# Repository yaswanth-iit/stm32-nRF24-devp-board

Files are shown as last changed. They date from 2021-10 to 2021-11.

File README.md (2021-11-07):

# STM32-nRF24 RF devpelopment board
This repository contains STM32 nRF24 development board schematics, PCB layout, output files (Designed using kiCAD) [4-Layer]

[Schematics](https://raw.githubusercontent.com/yaswanth-iit/stm32-nRF24-devp-board/master/quick%20view/schematics-stm32-nrf24.pdf)

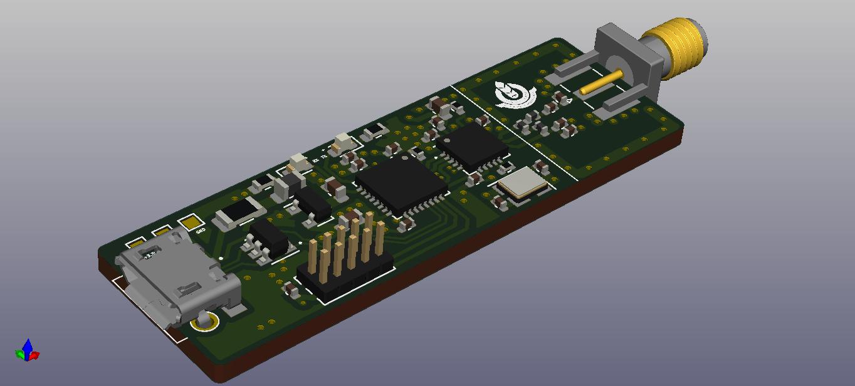
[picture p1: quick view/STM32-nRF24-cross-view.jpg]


# Top View

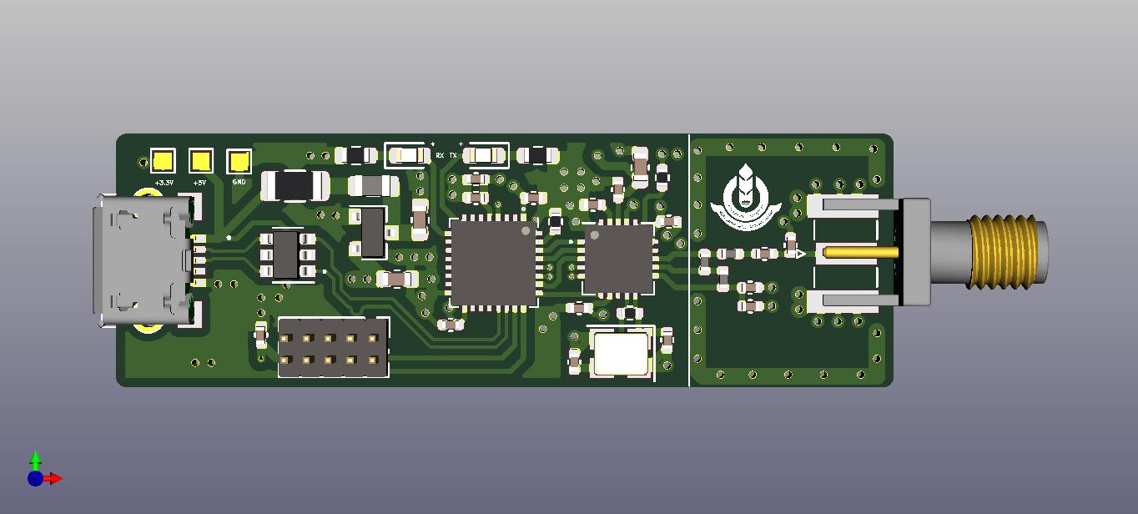
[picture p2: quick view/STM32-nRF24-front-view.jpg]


# Bottom view

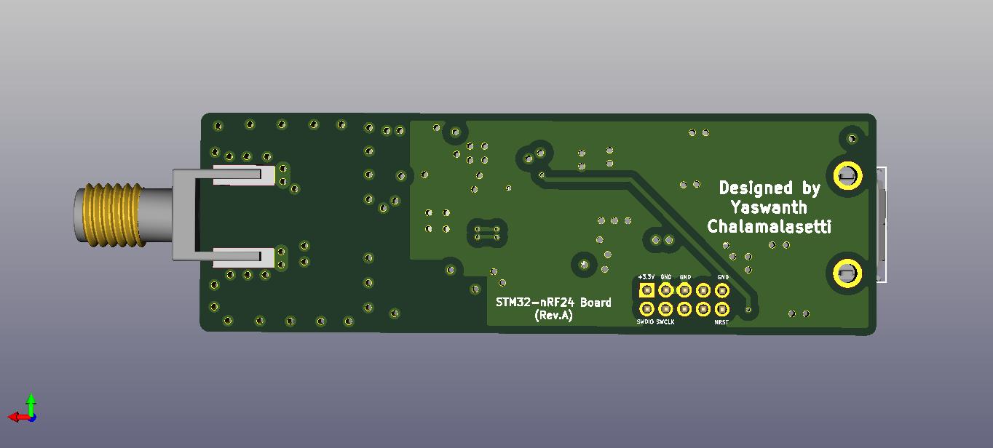
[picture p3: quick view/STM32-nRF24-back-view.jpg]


# PCB Layout

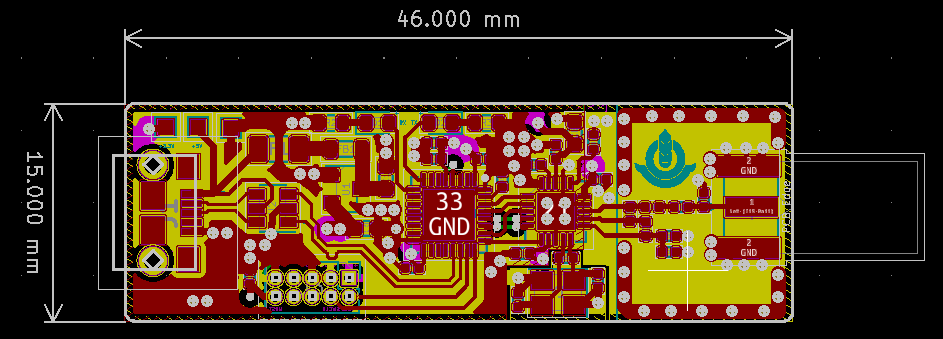
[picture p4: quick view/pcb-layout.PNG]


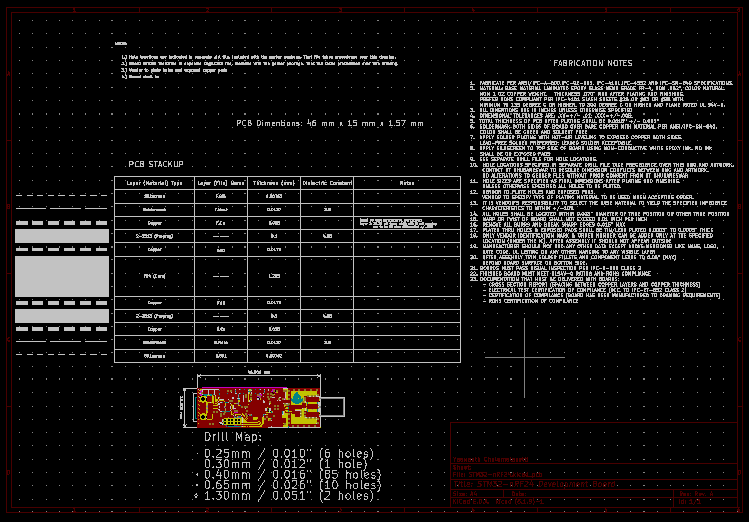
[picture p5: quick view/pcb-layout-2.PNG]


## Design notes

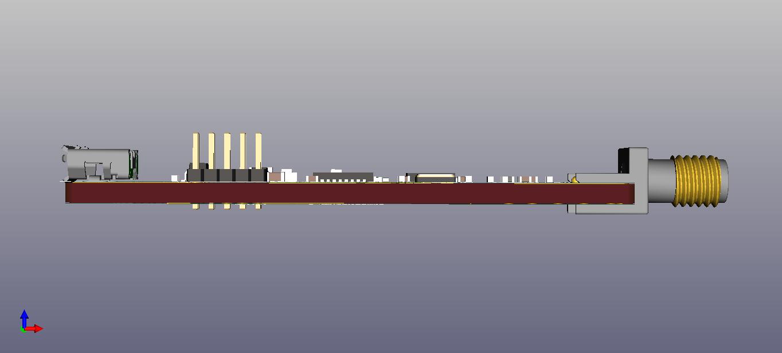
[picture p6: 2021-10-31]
quick view/STM32-nRF24-side-view.jpg

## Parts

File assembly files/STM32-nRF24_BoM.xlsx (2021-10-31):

Item | Qty | Reference(s) | Value | Description | Component name : PCB footprint | Manufacturer | Part Number | Availability status | Distributor
1 | 3 | C1, C2, C8, | 10u | Unpolarized capacitor | Capacitor_SMD:C_0603_1608Metric
2 | 4 | C3, C5, C6, C7, | 100n | Unpolarized capacitor | Capacitor_SMD:C_0402_1005Metric
3 | 1 | C4, | 1u | Unpolarized capacitor | Capacitor_SMD:C_0402_1005Metric
4 | 3 | C9, C10, C11, | 10n | Unpolarized capacitor | Capacitor_SMD:C_0402_1005Metric
5 | 1 | C12, | 33n | Unpolarized capacitor | Capacitor_SMD:C_0402_1005Metric
6 | 2 | C13, C14, | 12p | Unpolarized capacitor | Capacitor_SMD:C_0402_1005Metric
7 | 1 | C15, | 1p5 | Unpolarized capacitor | Capacitor_SMD:C_0402_1005Metric
8 | 1 | C16, | 1p | Unpolarized capacitor | Capacitor_SMD:C_0402_1005Metric
9 | 1 | C17, | 2n2 | Unpolarized capacitor | Capacitor_SMD:C_0402_1005Metric
10 | 1 | C18, | 4p7 | Unpolarized capacitor | Capacitor_SMD:C_0402_1005Metric
11 | 1 | D1, | GR | Light emitting diode | LED_SMD:LED_0603_1608Metric
12 | 1 | D2, | YE | Light emitting diode | LED_SMD:LED_0603_1608Metric
13 | 1 | F1, | 100mA | Fuse | Fuse:Fuse_1206_3216Metric
14 | 1 | FB1, | 100 @ 100MHz | Ferrite bead | Inductor_SMD:L_0805_2012Metric
15 | 1 | J1, | USB_B_Micro | USB Micro Type B connector | 10118193-0001LF:101181930001LF
16 | 1 | J2, | SMA | coaxial connector (BNC, SMA, SMB, SMC, Cinch/RCA, ...) | Connector_Coaxial:SMA_Samtec_SMA-J-P-X-ST-EM1_EdgeMount
17 | 1 | J3, | ARM 10pin | Generic connector, double row, 02x05, odd/even pin numbering scheme (row 1 odd numbers, row 2 even numbers), script generated (kicad-library-utils/schlib/autogen/connector/) | Connector_PinHeader_1.27mm:PinHeader_2x05_P1.27mm_Vertical
18 | 1 | L1, | 3n9 | Inductor | Inductor_SMD:L_0402_1005Metric
19 | 1 | L2, | 8n2 | Inductor | Inductor_SMD:L_0402_1005Metric
20 | 1 | L3, | 2n7 | Inductor | Inductor_SMD:L_0402_1005Metric
21 | 1 | R1, | 10k | Resistor | Resistor_SMD:R_0402_1005Metric
22 | 2 | R2, R3, | 2k2 | Resistor | Resistor_SMD:R_0603_1608Metric
23 | 1 | R4, | 22k | Resistor | Resistor_SMD:R_0402_1005Metric
24 | 1 | R5, | 1M | Resistor | Resistor_SMD:R_0402_1005Metric
25 | 1 | U1, | XC6206P332MR | Positive 60-250mA Low Dropout Regulator, Fixed Output, SOT-23 | Package_TO_SOT_SMD:SOT-23
26 | 1 | U2, | USBLC6-2SC6 | Very low capacitance ESD protection diode, 2 data-line, SOT-23-6 | Package_TO_SOT_SMD:SOT-23-6
27 | 1 | U3, | STM32L432KBU6 | ARM Cortex-M4 MCU, 128KB flash, 64KB RAM, 80MHz, 1.71-3.6V, 26 GPIO, UFQFPN-32 | Package_DFN_QFN:QFN-32-1EP_5x5mm_P0.5mm_EP3.45x3.45mm
28 | 1 | U4, | nRF24L01P | nRF24L01+, Ultra low power 2.4GHz RF Transceiver, QFN20 4x4mm | Package_DFN_QFN:QFN-20-1EP_4x4mm_P0.5mm_EP2.5x2.5mm
29 | 1 | Y1, | 16MHz | Four pin crystal, GND on pins 2 and 4, small symbol | Crystal:Crystal_SMD_3225-4Pin_3.2x2.5mm

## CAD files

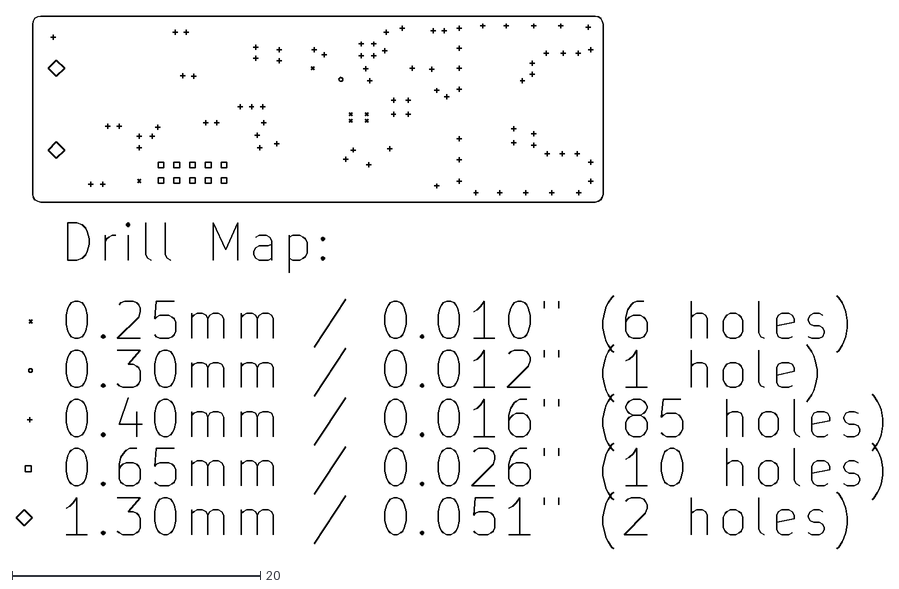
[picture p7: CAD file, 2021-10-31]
kicad-sch-pcb-files/STM32-nRF24-drl_map.dxf
69.9 x 43.0

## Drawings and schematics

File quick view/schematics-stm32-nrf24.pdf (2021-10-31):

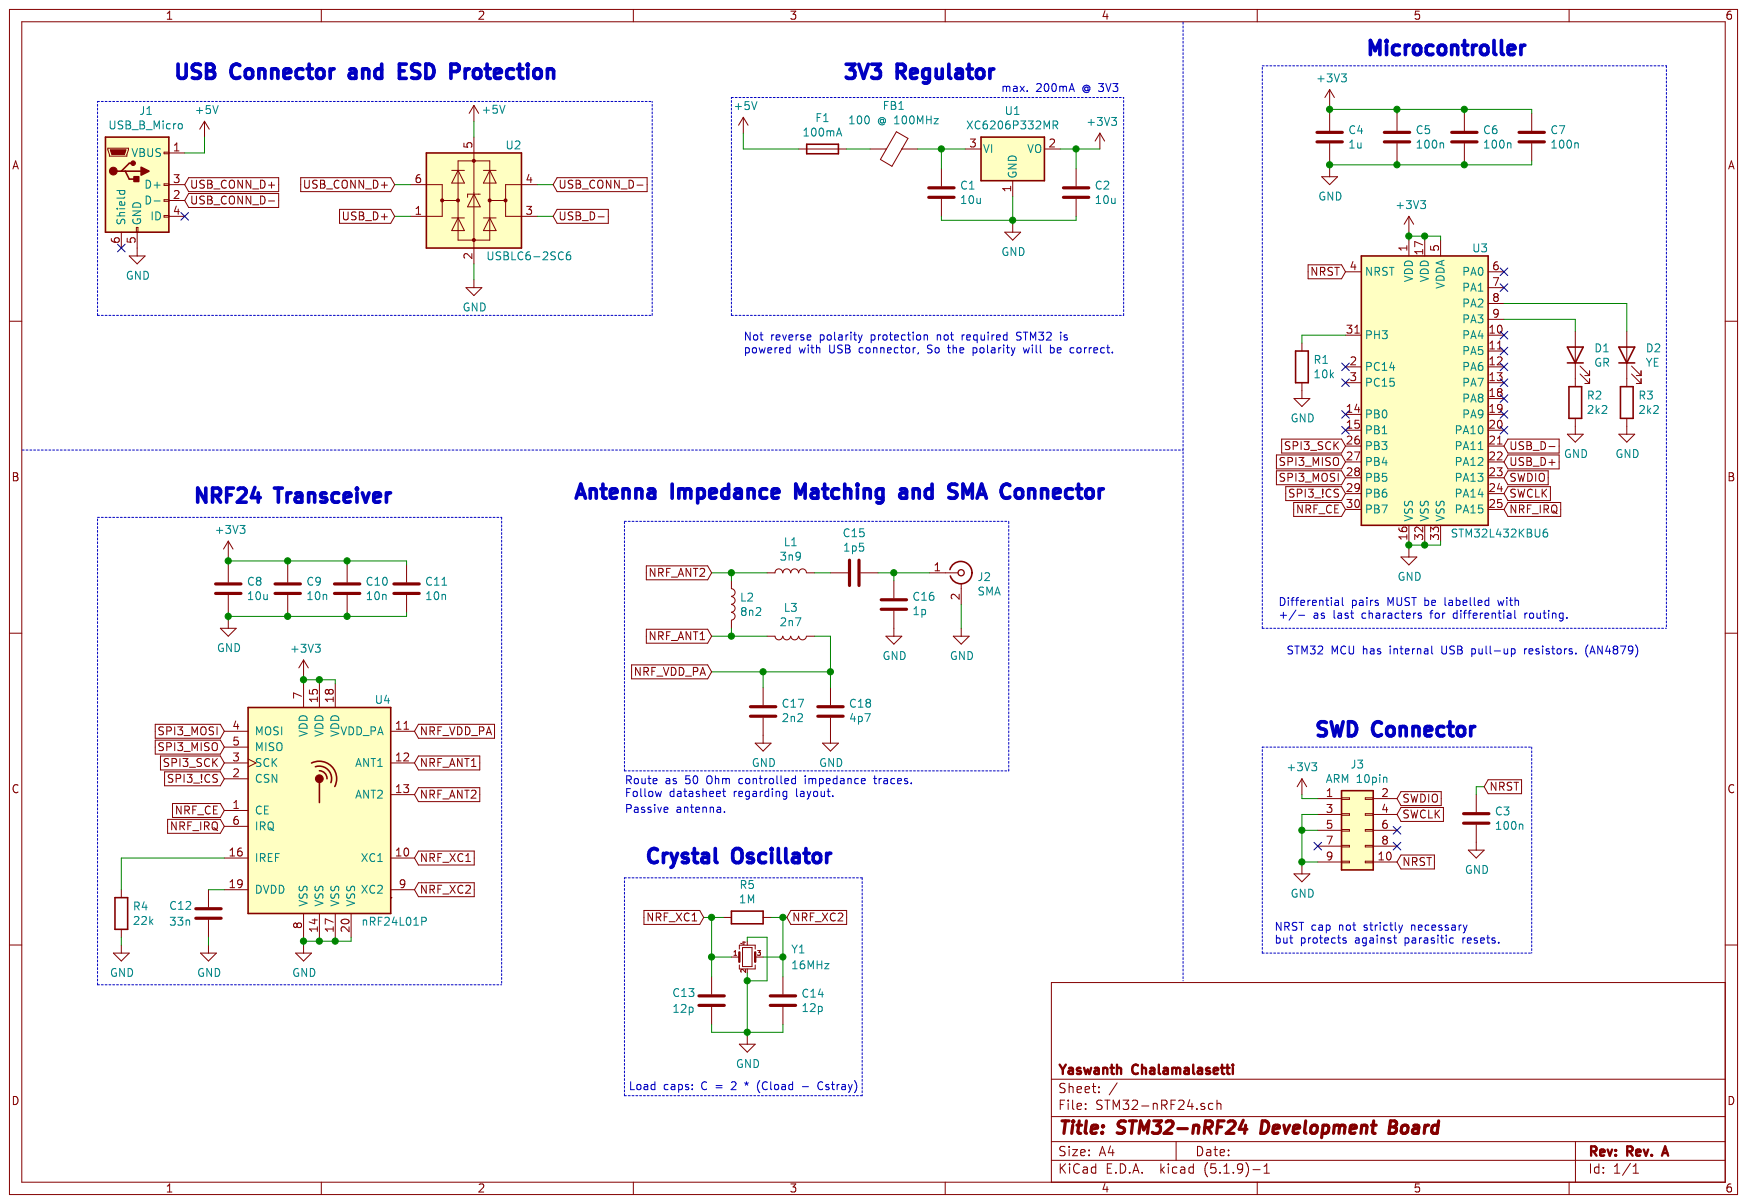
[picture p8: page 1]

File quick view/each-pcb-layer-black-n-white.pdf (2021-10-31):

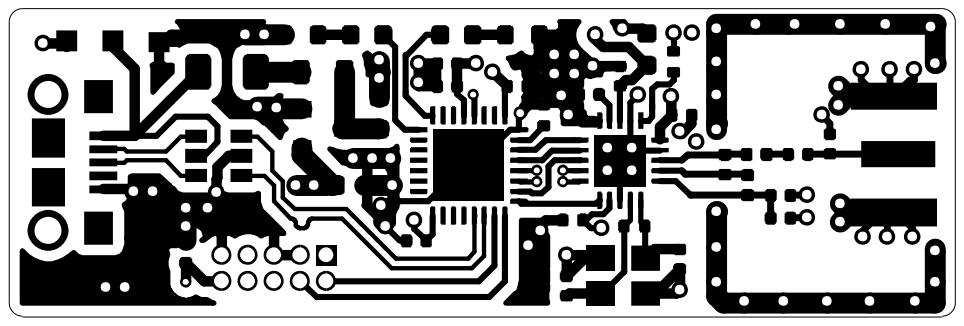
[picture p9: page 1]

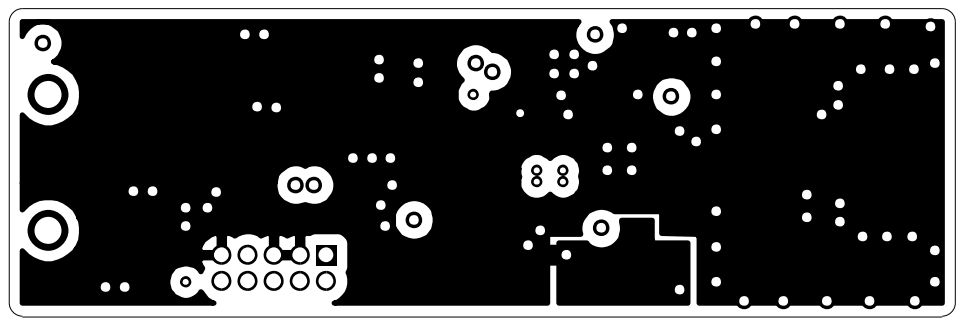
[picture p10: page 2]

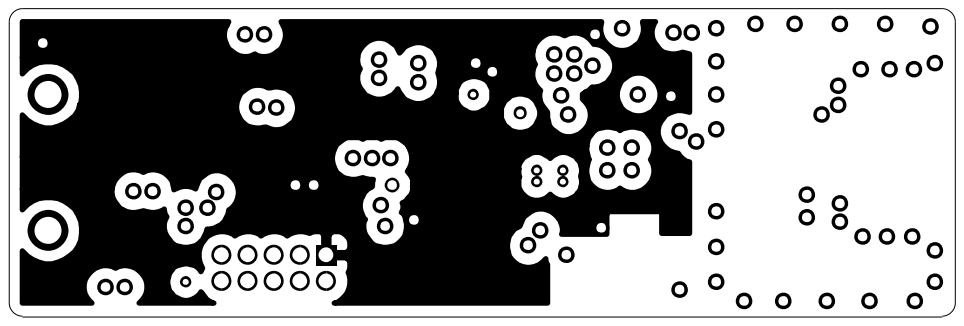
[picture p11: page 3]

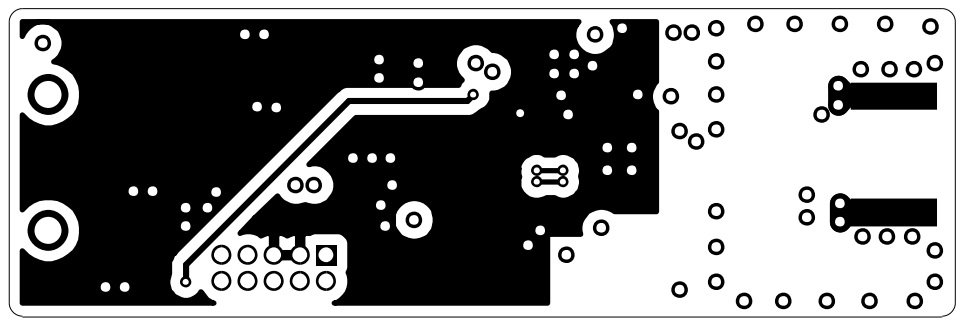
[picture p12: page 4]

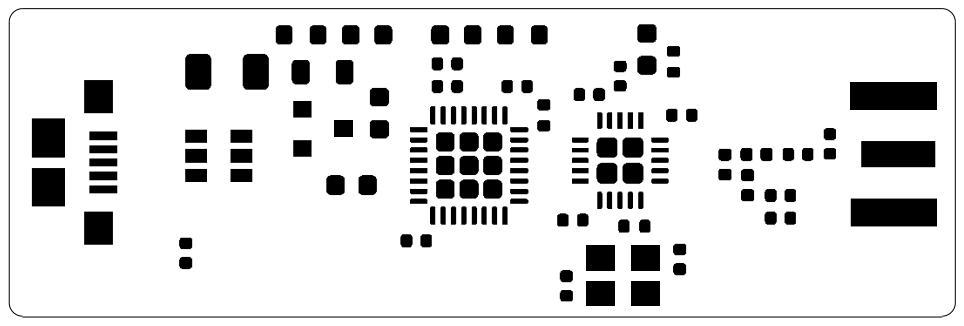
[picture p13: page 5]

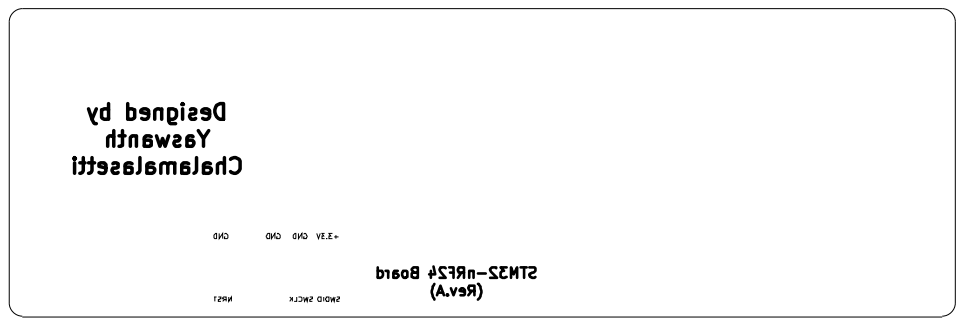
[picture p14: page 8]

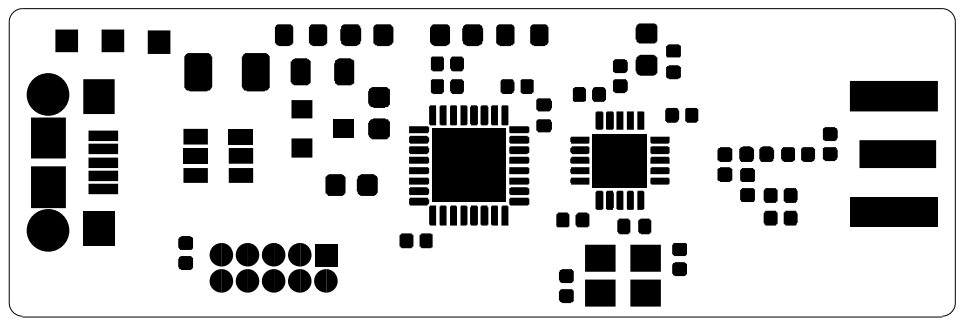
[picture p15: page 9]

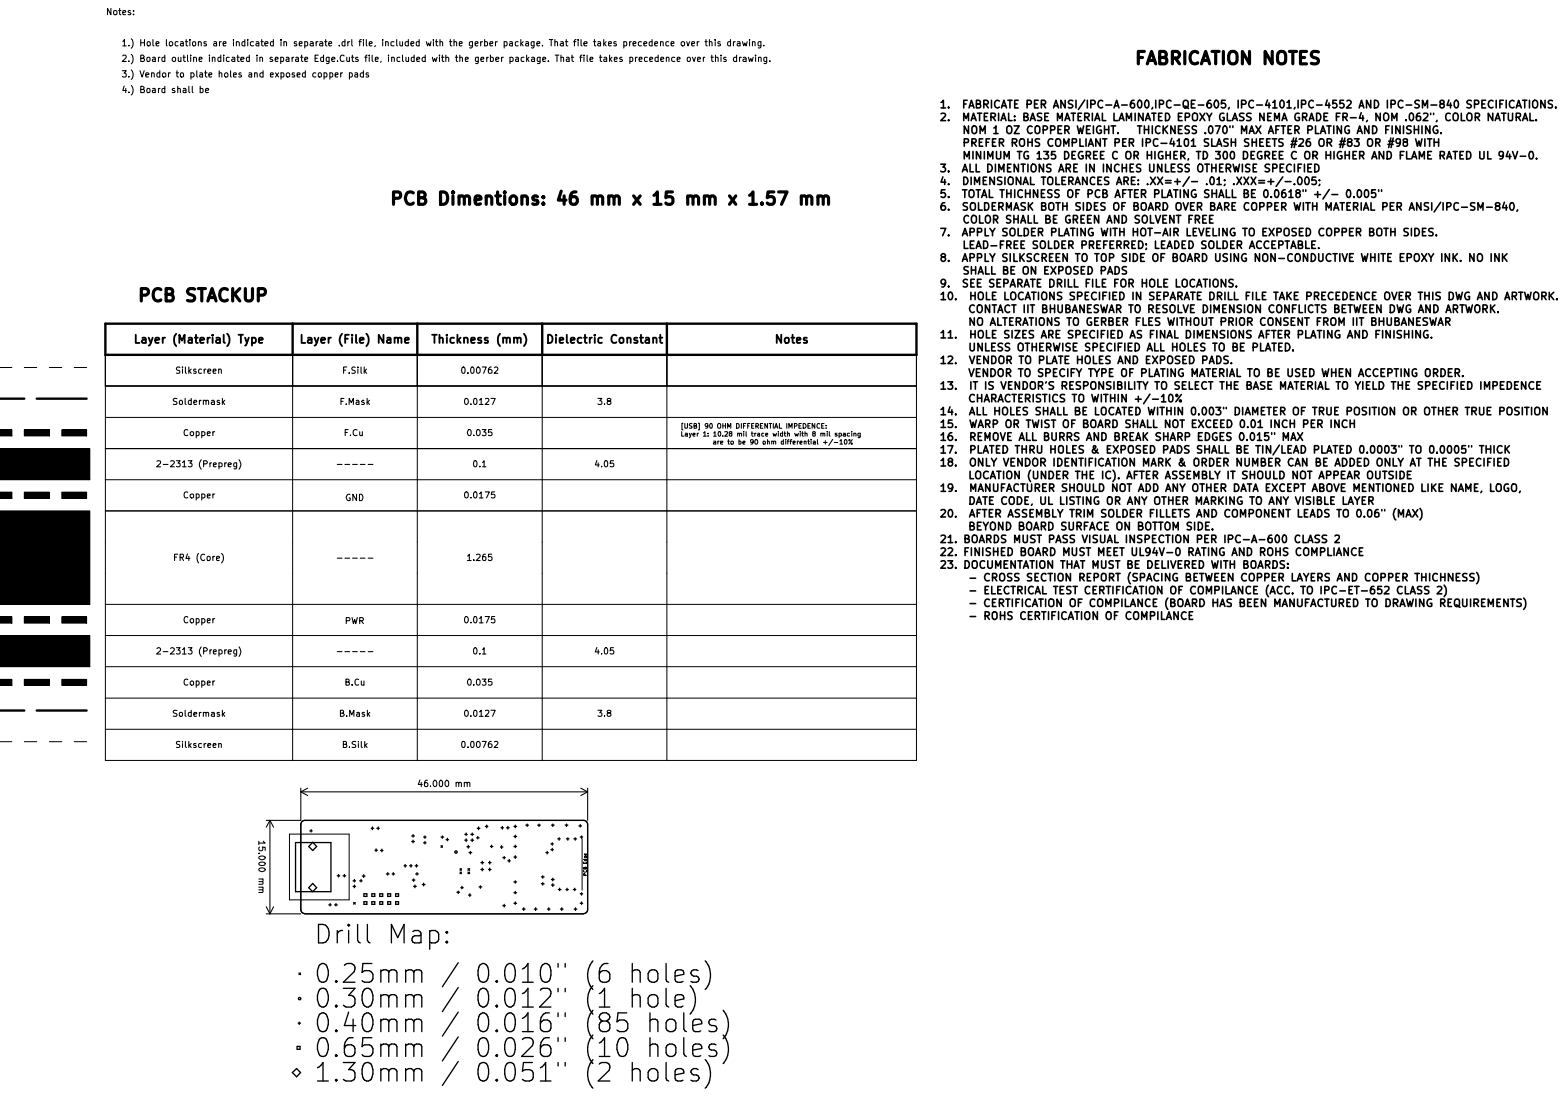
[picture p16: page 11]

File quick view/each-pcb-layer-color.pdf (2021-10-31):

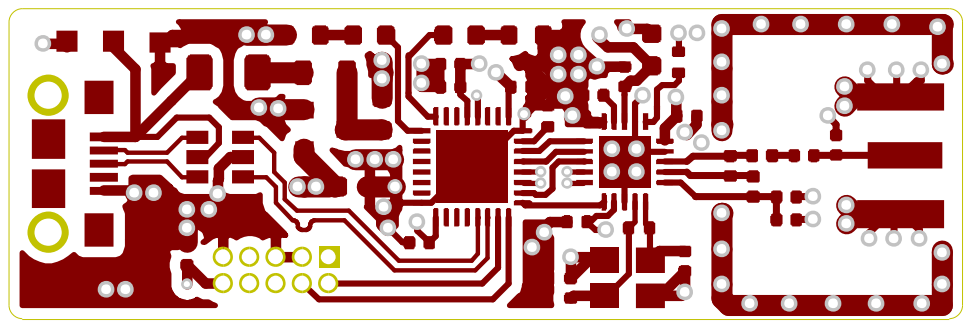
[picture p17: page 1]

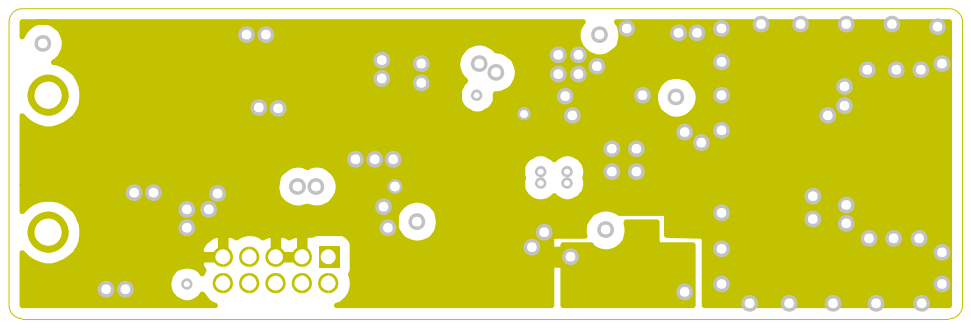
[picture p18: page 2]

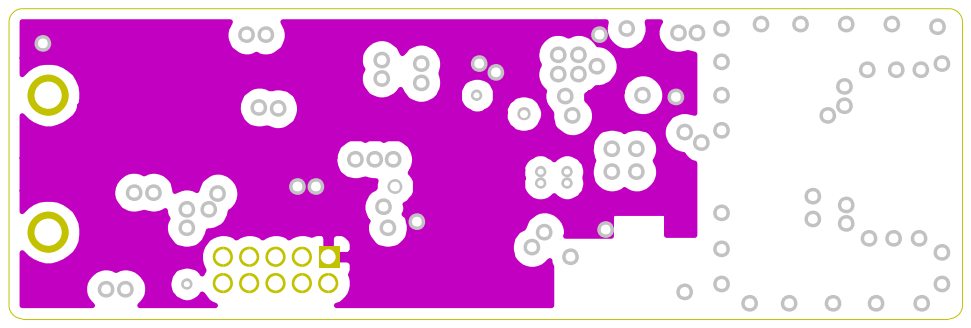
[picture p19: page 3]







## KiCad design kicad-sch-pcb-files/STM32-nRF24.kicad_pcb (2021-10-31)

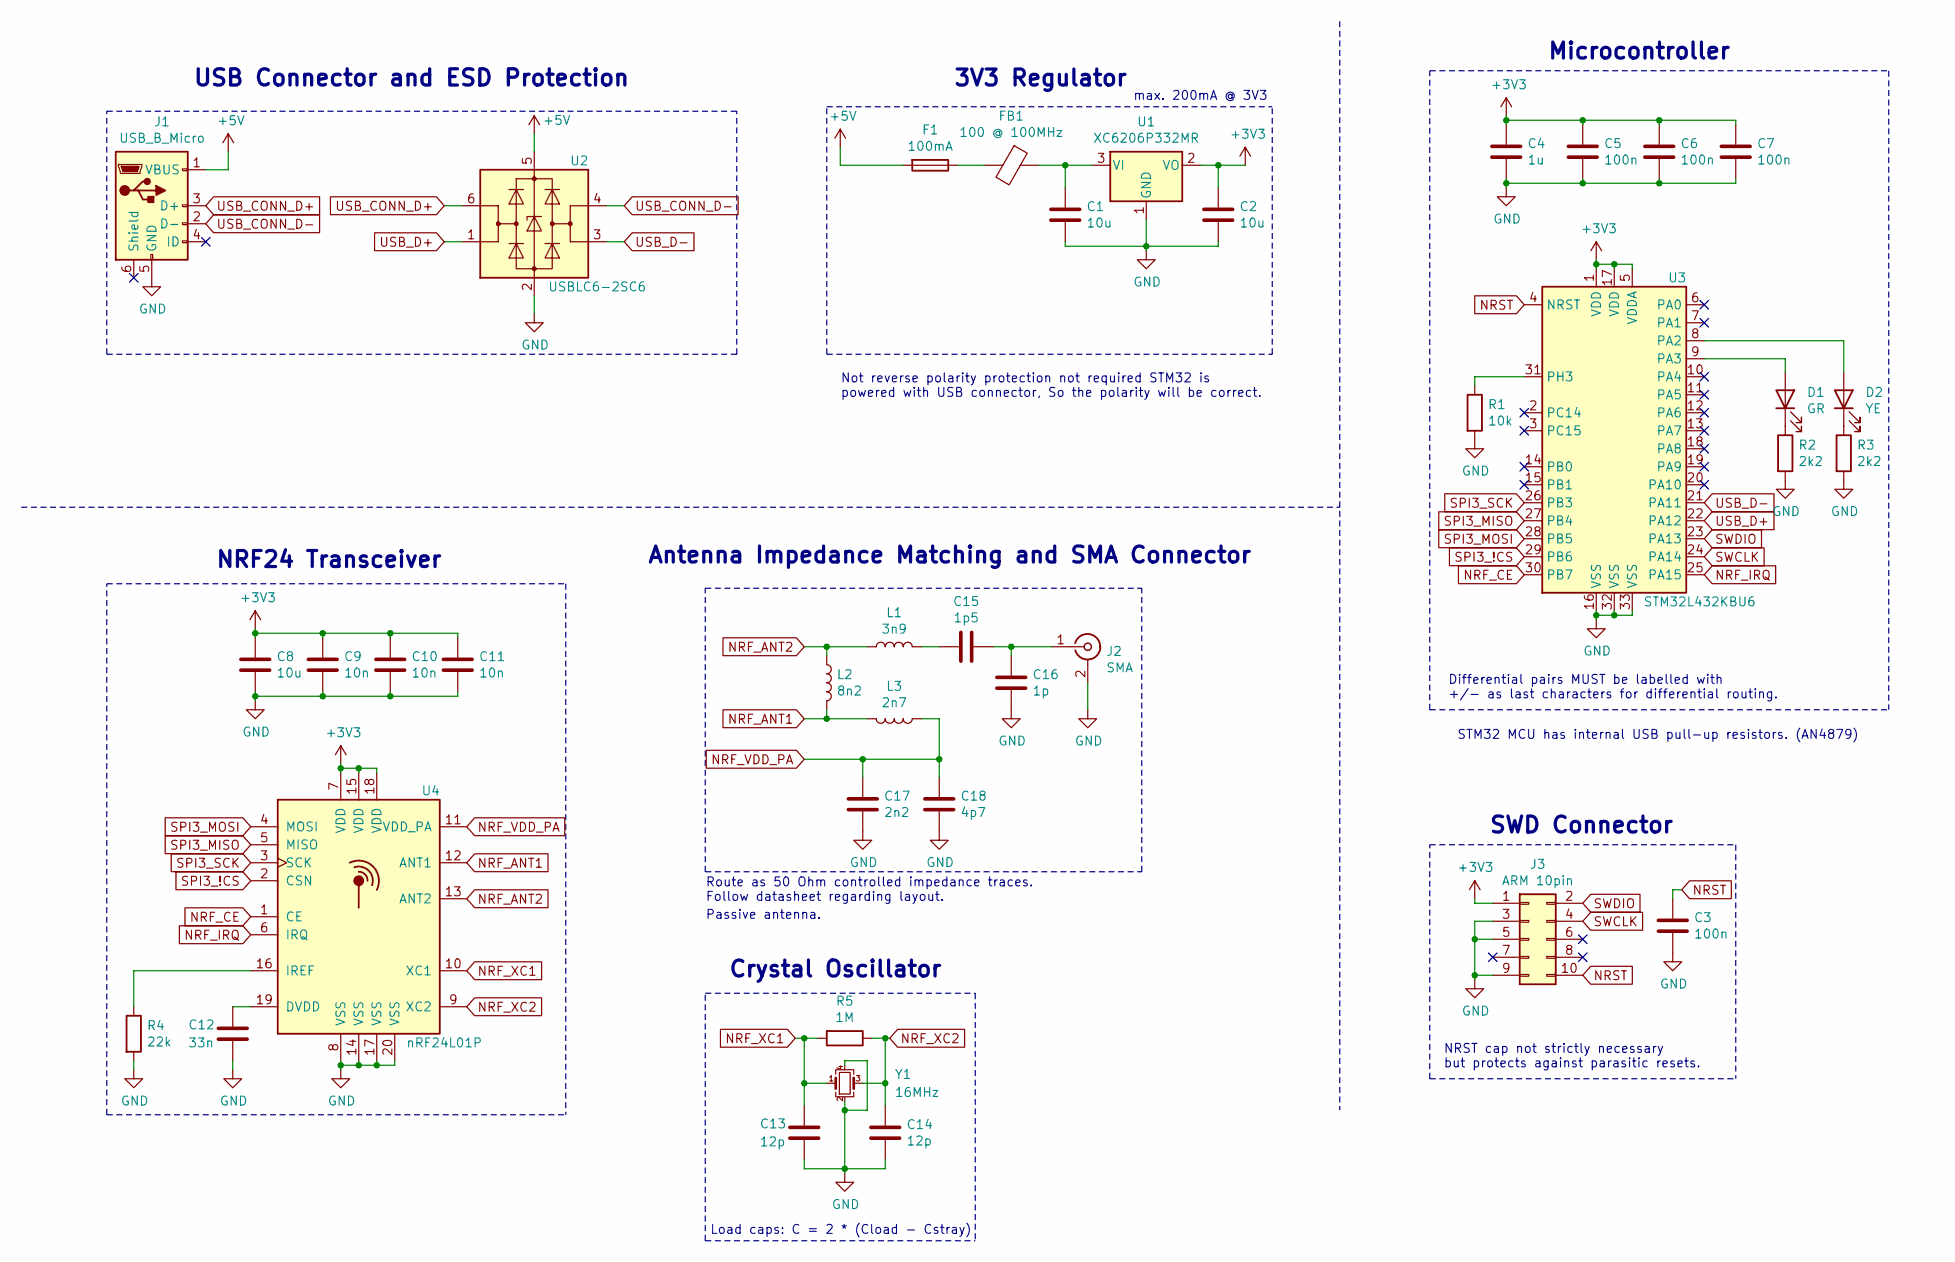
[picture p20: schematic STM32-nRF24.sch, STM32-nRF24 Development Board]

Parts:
C1, C2, C8: 10u; C_0603_1608Metric
C3, C5, C6, C7: 100n; C_0402_1005Metric
C4: 1u; C_0402_1005Metric
C9, C10, C11: 10n; C_0402_1005Metric
C12: 33n; C_0402_1005Metric
C13, C14: 12p; C_0402_1005Metric
C15: 1p5; C_0402_1005Metric
C16: 1p; C_0402_1005Metric
C17: 2n2; C_0402_1005Metric
C18: 4p7; C_0402_1005Metric
D1: GR; LED_0603_1608Metric
D2: YE; LED_0603_1608Metric
F1: 100mA; Fuse_1206_3216Metric
FB1: 100 @ 100MHz; L_0805_2012Metric
J1: USB_B_Micro; 101181930001LF
J2: SMA; SMA_Samtec_SMA-J-P-X-ST-EM1_EdgeMount
J3: ARM 10pin; PinHeader_2x05_P1.27mm_Vertical
L1: 3n9; L_0402_1005Metric
L2: 8n2; L_0402_1005Metric
L3: 2n7; L_0402_1005Metric
R1: 10k; R_0402_1005Metric
R2, R3: 2k2; R_0603_1608Metric
R4: 22k; R_0402_1005Metric
R5: 1M; R_0402_1005Metric
U1: XC6206P332MR; SOT-23
U2: USBLC6-2SC6; SOT-23-6
U3: STM32L432KBU6; QFN-32-1EP_5x5mm_P0.5mm_EP3.45x3.45mm
U4: nRF24L01P; QFN-20-1EP_4x4mm_P0.5mm_EP2.5x2.5mm
Y1: 16MHz; Crystal_SMD_3225-4Pin_3.2x2.5mm

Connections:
+3V3: C2.1, C4.1, C5.1, C6.1, C7.1, C8.1, C9.1, C10.1, C11.1, J3.1, U1.2 (VO), U3.1 (VDD), U3.5 (VDDA), U3.17 (VDD), U4.7 (VDD), U4.15 (VDD), U4.18 (VDD); also elsewhere on the board
+5V: F1.2, J1.1 (VBUS), U2.5 (VBUS); also elsewhere on the board
GND: C1.2, C2.2, C3.2, C4.2, C5.2, C6.2, C7.2, C8.2, C9.2, C10.2, C11.2, C12.2, C13.2, C14.2, C16.1, C17.1, C18.1, J1.5 (GND), J2.2 (Ext), J3.3, J3.5, J3.9, R1.2, R2.2, R3.2, R4.2, U1.1 (GND), U2.2 (GND), U3.16 (VSS), U3.32 (VSS), U3.33 (VSS), U4.8 (VSS), U4.14 (VSS), U4.17 (VSS), U4.20 (VSS), Y1.2, Y1.4
NRF_ANT1: L2.2, L3.2, U4.12 (ANT1)
NRF_ANT2: L1.1, L2.1, U4.13 (ANT2)
NRF_CE: U3.30 (PB7), U4.1 (CE)
NRF_IRQ: U3.25 (PA15), U4.6 (IRQ)
NRF_VDD_PA: C17.2, C18.2, L3.1, U4.11 (VDD_PA)
NRF_XC1: C13.1, R5.2, U4.10 (XC1), Y1.1
NRF_XC2: C14.1, R5.1, U4.9 (XC2), Y1.3
NRST: C3.1, J3.10, U3.4 (NRST)
unnamed: C1.1, FB1.1, U1.3 (VI)
unnamed: C12.1, U4.19 (DVDD)
unnamed: C15.1, C16.2, J2.1 (In)
unnamed: C15.2, L1.2
unnamed: D1.1 (K), R2.1
unnamed: D1.2 (A), U3.9 (PA3)
unnamed: D2.1 (K), R3.1
unnamed: D2.2 (A), U3.8 (PA2)
unnamed: F1.1, FB1.2
unnamed: R1.1, U3.31 (PH3)
unnamed: R4.1, U4.16 (IREF)
SPI3_!CS: U3.29 (PB6), U4.2 (CSN)
SPI3_MISO: U3.27 (PB4), U4.5 (MISO)
SPI3_MOSI: U3.28 (PB5), U4.4 (MOSI)
SPI3_SCK: U3.26 (PB3), U4.3 (SCK)
SWCLK: J3.4, U3.24 (PA14)
SWDIO: J3.2, U3.23 (PA13)
USB_CONN_D+: J1.3 (D+), U2.6 (I/O1)
USB_CONN_D-: J1.2 (D-), U2.4 (I/O2)
USB_D+: U2.1 (I/O1), U3.22 (PA12)
USB_D-: U2.3 (I/O2), U3.21 (PA11)

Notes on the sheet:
NRST cap not strictly necessary but protects against parasitic resets.
Differential pairs MUST be labelled with +/- as last characters for differential routing.
3V3 Regulator
Microcontroller
SWD Connector
STM32 MCU has internal USB pull-up resistors. (AN4879)
Not reverse polarity protection not required STM32 is powered with USB connector, So the polarity will be correct.
Load caps: C = 2 * (Cload - Cstray)
NRF24 Transceiver
Crystal Oscillator
USB Connector and ESD Protection
Antenna Impedance Matching and SMA Connector
Route as 50 Ohm controlled impedance traces. Follow datasheet regarding layout.
Passive antenna.
max. 200mA @ 3V3

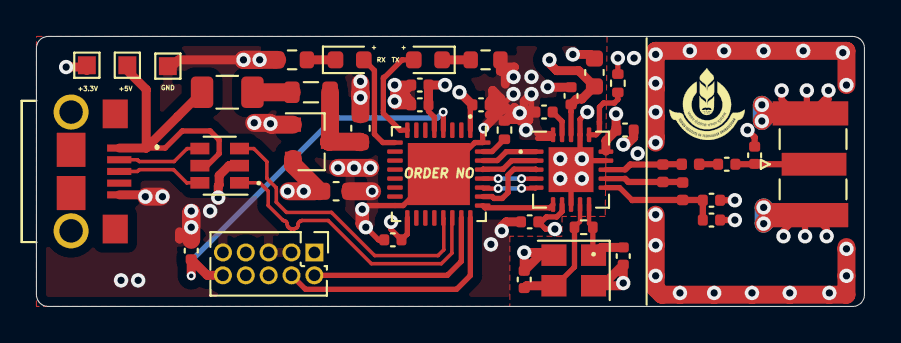
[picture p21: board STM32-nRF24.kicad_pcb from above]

Board: 4 copper layers, 46.0 x 15.0 mm, 40 parts (0 on the bottom side), 32 nets.

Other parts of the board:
3v3, 5v: TestPoint_Pad_1.0x1.0mm

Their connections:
+3V3: 3v3.1; also elsewhere on the board
+5V: 5v.1; also elsewhere on the board

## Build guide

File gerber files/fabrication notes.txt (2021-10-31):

1.  FABRICATE PER ANSI/IPC-A-600,IPC-QE-605, IPC-4101,IPC-4552 AND IPC-SM-840 SPECIFICATIONS. 
2.  MATERIAL: BASE MATERIAL LAMINATED EPOXY GLASS NEMA GRADE FR-4, NOM .062", COLOR NATURAL.  
    NOM 1 OZ COPPER WEIGHT.   THICKNESS .070" MAX AFTER PLATING AND FINISHING.  
    PREFER ROHS COMPLIANT PER IPC-4101 SLASH SHEETS #26 OR #83 OR #98 WITH 
    MINIMUM TG 135 DEGREE C OR HIGHER, TD 300 DEGREE C OR HIGHER AND FLAME RATED UL 94V-0.
3.  ALL DIMENTIONS ARE IN INCHES UNLESS OTHERWISE SPECIFIED
4.  DIMENSIONAL TOLERANCES ARE: .XX=+/- .01; .XXX=+/-.005;
5.  TOTAL THICHNESS OF PCB AFTER PLATING SHALL BE 0.0618" +/- 0.005"
6.  SOLDERMASK BOTH SIDES OF BOARD OVER BARE COPPER WITH MATERIAL PER ANSI/IPC-SM-840, 
    COLOR SHALL BE GREEN AND SOLVENT FREE
7.  APPLY SOLDER PLATING WITH HOT-AIR LEVELING TO EXPOSED COPPER BOTH SIDES.  
    LEAD-FREE SOLDER PREFERRED; LEADED SOLDER ACCEPTABLE.
8.  APPLY SILKSCREEN TO TOP SIDE OF BOARD USING NON-CONDUCTIVE WHITE EPOXY INK. NO INK SHALL BE ON EXPOSED PADS
9.  SEE SEPARATE DRILL FILE FOR HOLE LOCATIONS.  
10.  HOLE LOCATIONS SPECIFIED IN SEPARATE DRILL FILE TAKE PRECEDENCE OVER THIS DWG AND ARTWORK. 
     CONTACT IIT BHUBANESWAR TO RESOLVE DIMENSION CONFLICTS BETWEEN DWG AND ARTWORK.
     NO ALTERATIONS TO GERBER FLES WITHOUT PRIOR CONSENT FROM IIT BHUBANESWAR
11.  HOLE SIZES ARE SPECIFIED AS FINAL DIMENSIONS AFTER PLATING AND FINISHING.  
     UNLESS OTHERWISE SPECIFIED ALL HOLES TO BE PLATED. 
12.  VENDOR TO PLATE HOLES AND EXPOSED PADS.
     VENDOR TO SPECIFY TYPE OF PLATING MATERIAL TO BE USED WHEN ACCEPTING ORDER.
13.  IT IS VENDOR'S RESPONSIBILITY TO SELECT THE BASE MATERIAL TO YIELD THE SPECIFIED IMPEDENCE CHARACTERISTICS TO WITHIN +/-10%
14.  ALL HOLES SHALL BE LOCATED WITHIN 0.003" DIAMETER OF TRUE POSITION OR OTHER TRUE POSITION
15.  WARP OR TWIST OF BOARD SHALL NOT EXCEED 0.01 INCH PER INCH
16.  REMOVE ALL BURRS AND BREAK SHARP EDGES 0.015" MAX
17.  PLATED THRU HOLES & EXPOSED PADS SHALL BE TIN/LEAD PLATED 0.0003" TO 0.0005" THICK
18.  ONLY VENDOR IDENTIFICATION MARK & ORDER NUMBER CAN BE ADDED ONLY AT THE SPECIFIED LOCATION (UNDER THE IC). AFTER ASSEMBLY IT SHOULD NOT APPEAR OUTSIDE
19.  MANUFACTURER SHOULD NOT ADD ANY OTHER DATA EXCEPT ABOVE MENTIONED LIKE NAME, LOGO, DATE CODE, UL LISTING OR ANY OTHER MARKING TO ANY VISIBLE LAYER
20.  AFTER ASSEMBLY TRIM SOLDER FILLETS AND COMPONENT LEADS TO 0.06" (MAX) 
     BEYOND BOARD SURFACE ON BOTTOM SIDE.
21. BOARDS MUST PASS VISUAL INSPECTION PER IPC-A-600 CLASS 2
22. FINISHED BOARD MUST MEET UL94V-0 RATING AND ROHS COMPLIANCE
23. DOCUMENTATION THAT MUST BE DELIVERED WITH BOARDS:
	- CROSS SECTION REPORT (SPACING BETWEEN COPPER LAYERS AND COPPER THICHNESS)
	- ELECTRICAL TEST CERTIFICATION OF COMPILANCE (ACC. TO IPC-ET-652 CLASS 2)
	- CERTIFICATION OF COMPILANCE (BOARD HAS BEEN MANUFACTURED TO DRAWING REQUIREMENTS)
	- ROHS CERTIFICATION OF COMPILANCE
